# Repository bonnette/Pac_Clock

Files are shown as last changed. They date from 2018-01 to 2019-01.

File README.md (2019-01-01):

# Arduino Mega Pacman Clock
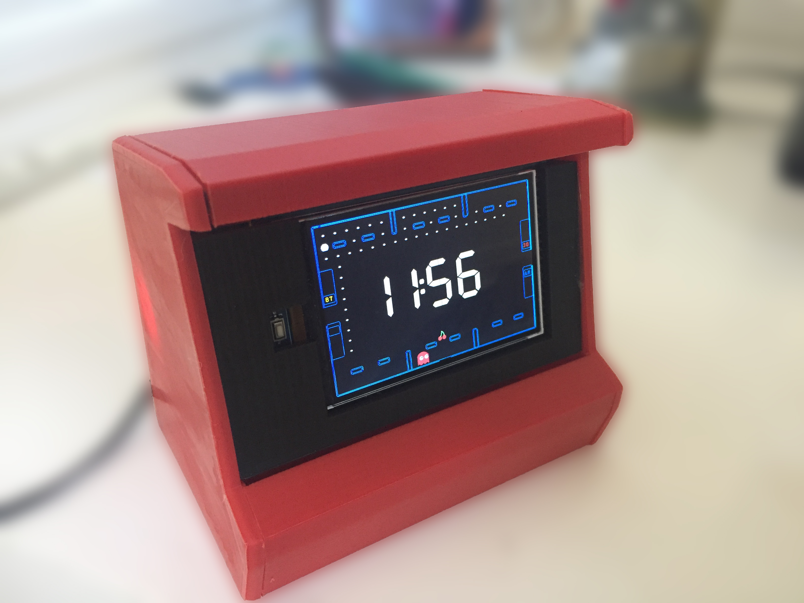
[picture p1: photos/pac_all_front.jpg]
Client Photo

<br/>
### There are more photos and information in the WIKI section of this repository
<br/>

This is modification of code from an Instructable by TechKiwiGadgets https://www.instructables.com/id/Retro-Pac-Man-Clock/
The purpose of the modification is to adapt the design to work with an HX8357C 480X320 TFT display <br/>(https://www.amazon.com/gp/product/B073R7Q8FF/ref=oh_aui_search_detailpage?ie=UTF8&psc=1).<br/>
And arduino Mega (https://www.amazon.com/gp/product/B01H4ZLZLQ/ref=oh_aui_search_detailpage?ie=UTF8&psc=1).
Additionally, because the display is not a touch display. Code has been added to use physical buttons to allow the time to be set on the clock.
<br />
The above photo is the clock in a 3d printed case. The case can be found on Thingiverse.com.<br/>
https://www.thingiverse.com/thing:2790349 <br/>
There is a newer version of the case that can be found here:<br/>
https://www.thingiverse.com/thing:3143466
<br />
The photo below shows the clock and RTC module.<br/>
Very bottom is a photo of the clock with larger font.
<br /><br />
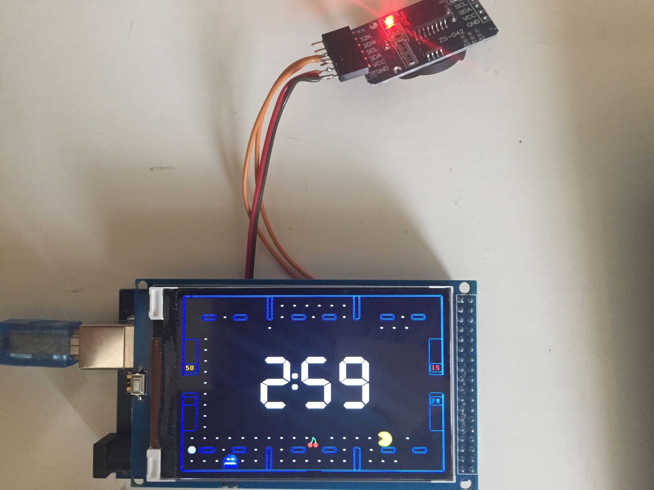
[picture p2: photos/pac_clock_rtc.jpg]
Client Photo

<br /><br />
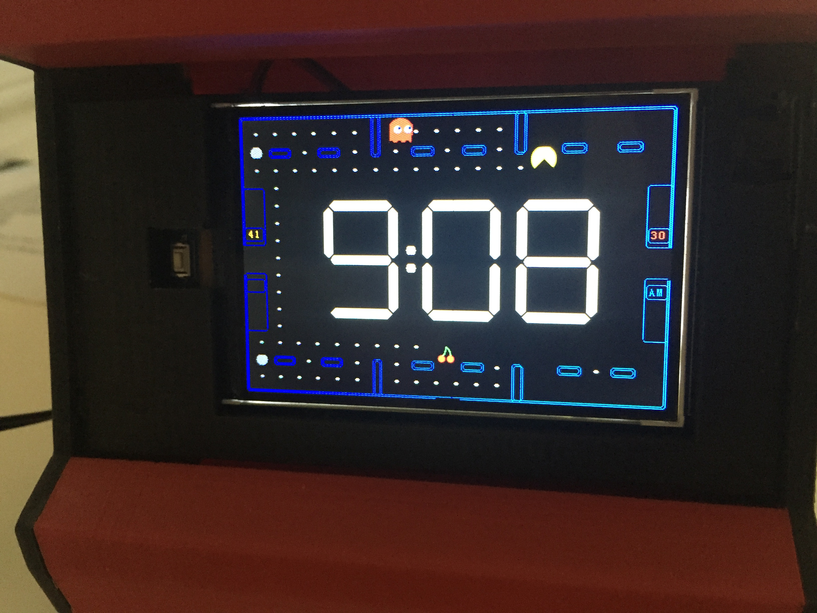
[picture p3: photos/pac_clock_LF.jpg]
Client Photo


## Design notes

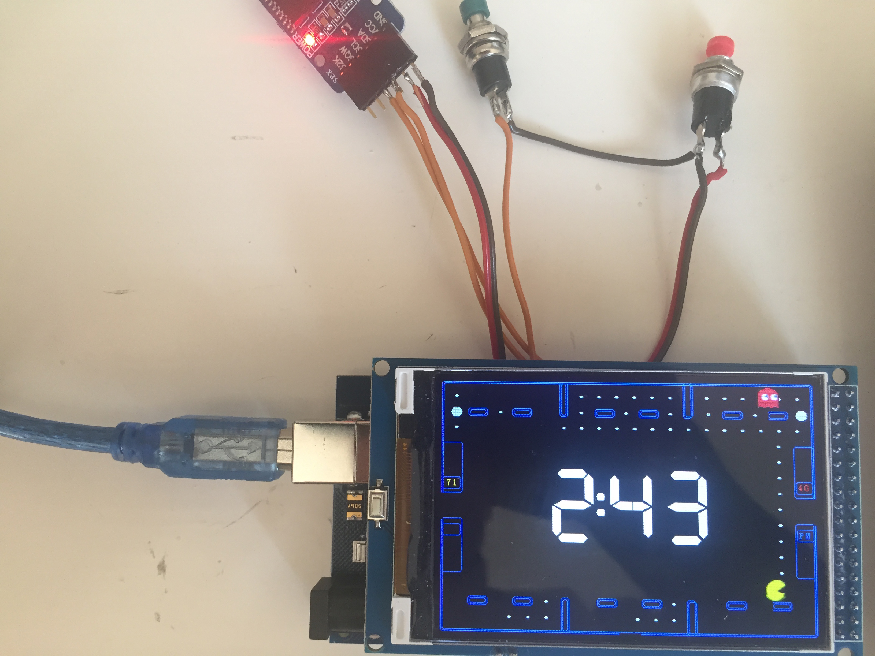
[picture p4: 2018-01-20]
photos/pac_clock_btn.jpg

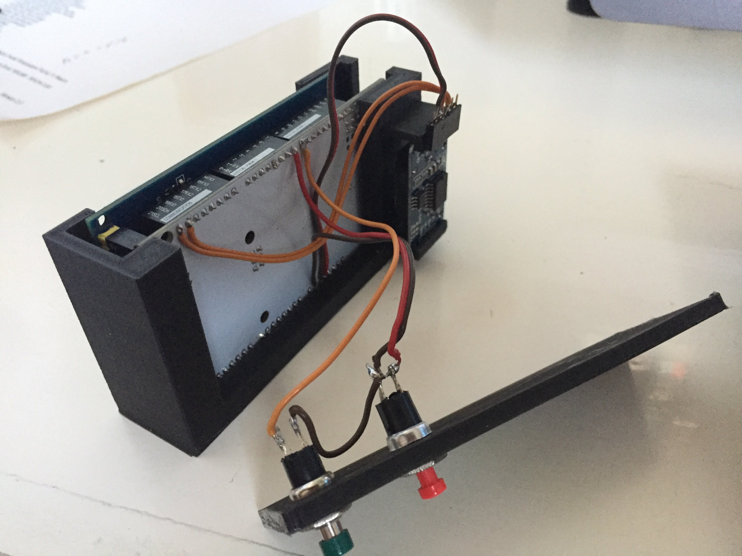
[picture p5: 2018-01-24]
photos/pac_cradle.jpg

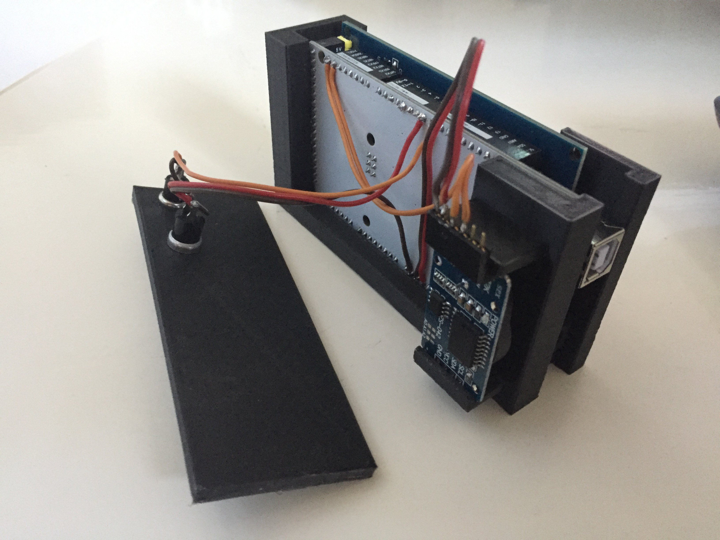
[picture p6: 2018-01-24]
photos/pac_cradle2.jpg

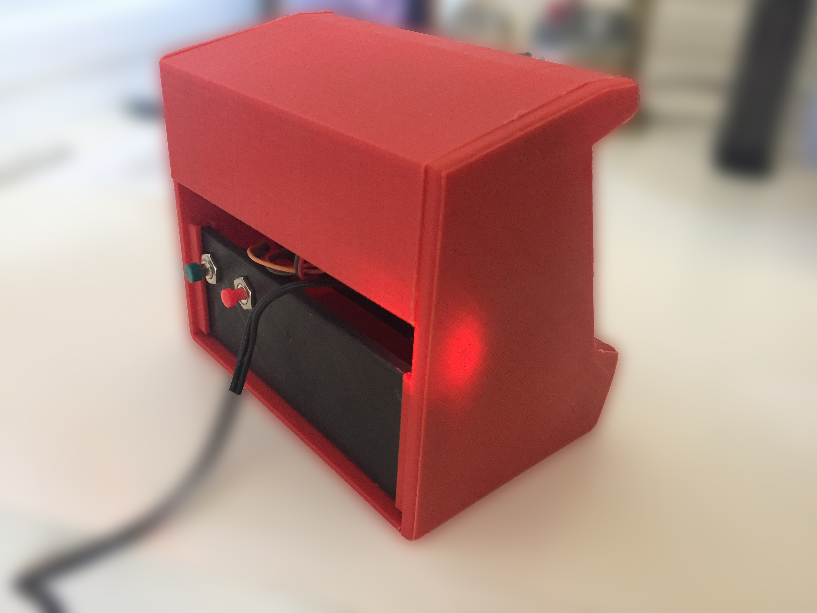
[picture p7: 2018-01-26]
photos/pac_all_back.jpg

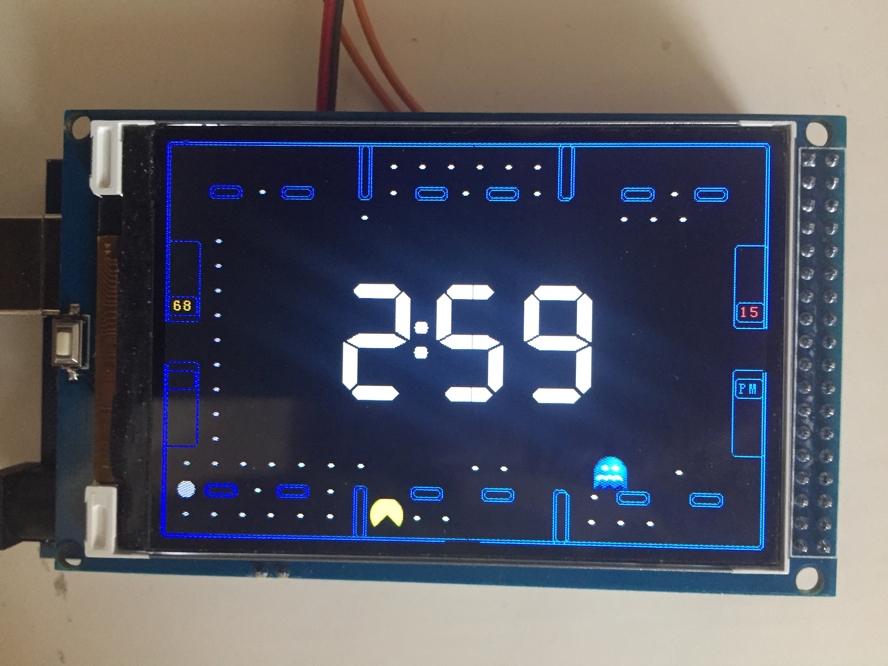
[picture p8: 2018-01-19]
photos/pac_clock.jpg

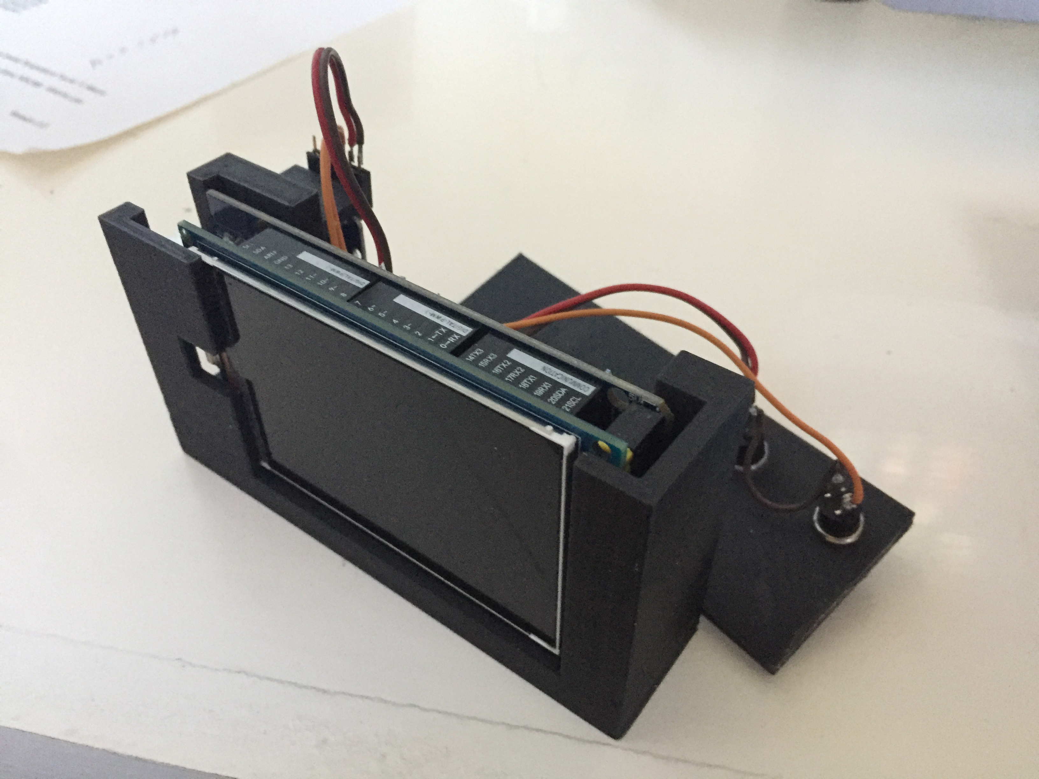
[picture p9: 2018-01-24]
photos/pac_cradle1.jpg

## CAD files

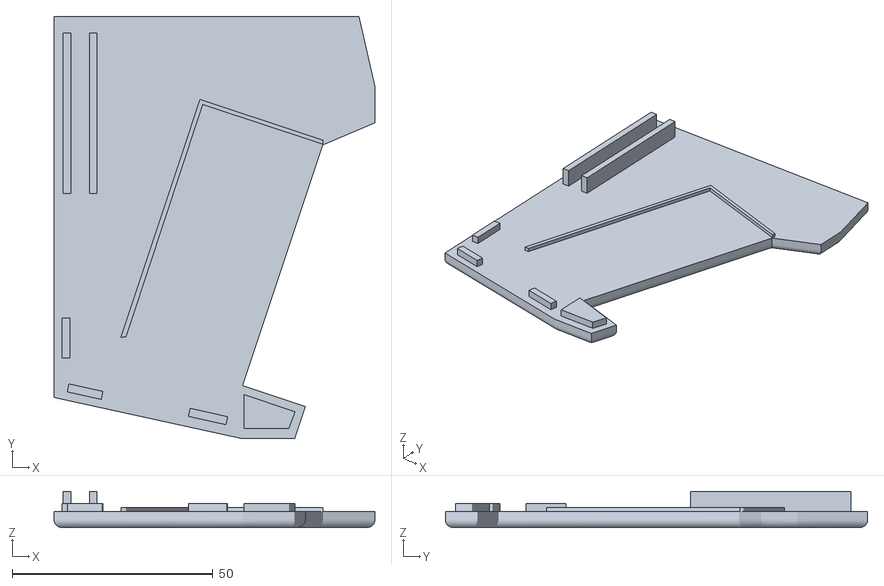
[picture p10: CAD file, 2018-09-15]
3D_Printed/pac_LS.stl
80.0 x 105.3 x 9.00

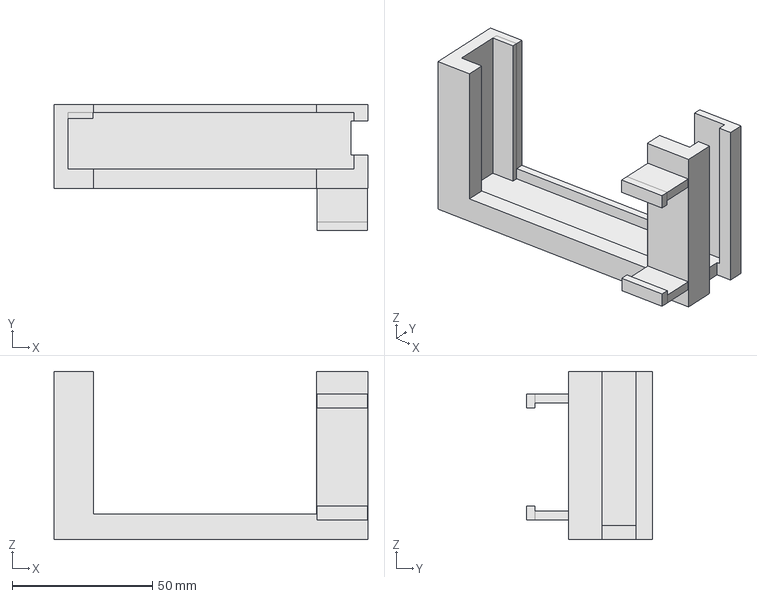
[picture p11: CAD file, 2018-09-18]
FreeCad/pac_clk_case_Cradle_HiLetgo.FCStd
112.0 x 45.0 x 60.0 mm

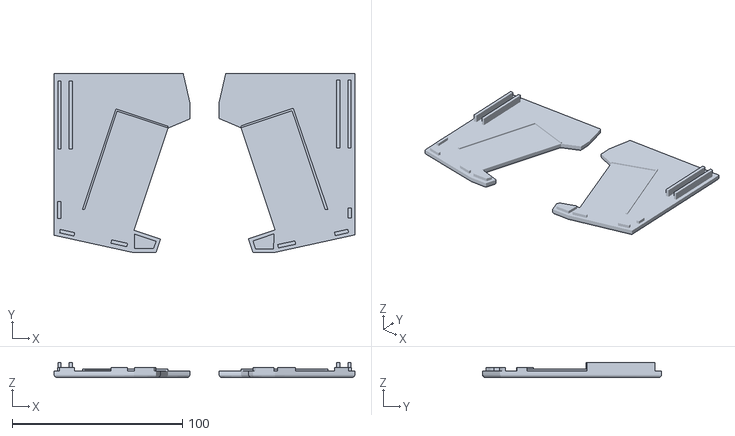
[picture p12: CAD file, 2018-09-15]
3D_Printed/pac_LS_RS.stl
177.0 x 105.5 x 9.00

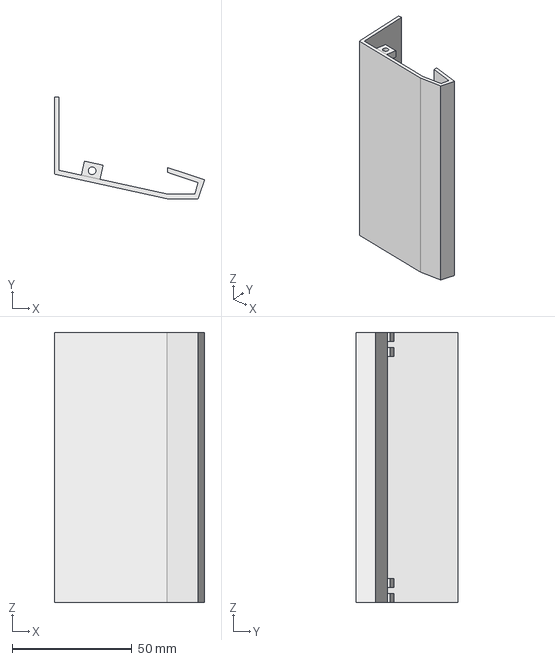
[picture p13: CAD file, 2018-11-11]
FreeCad/case_v2/pac_clk_case_Top.FCStd
62.7 x 42.3 x 112.5 mm

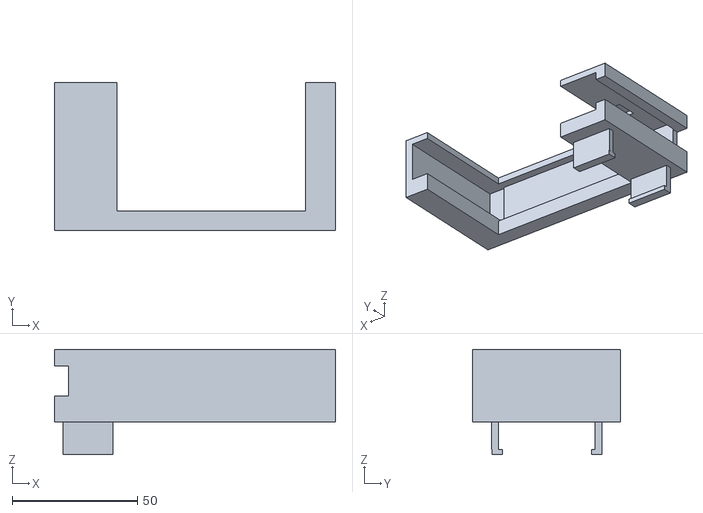
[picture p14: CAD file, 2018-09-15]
3D_Printed/pac_Cradle_no_reset.stl
112.0 x 59.0 x 42.0

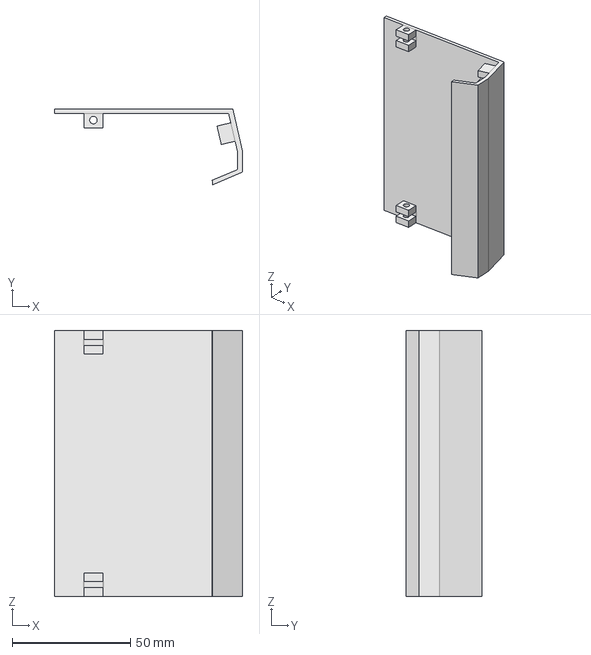
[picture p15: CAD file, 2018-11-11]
FreeCad/case_v2/pac_clk_case_Btm.FCStd
79.6 x 32.0 x 112.5 mm

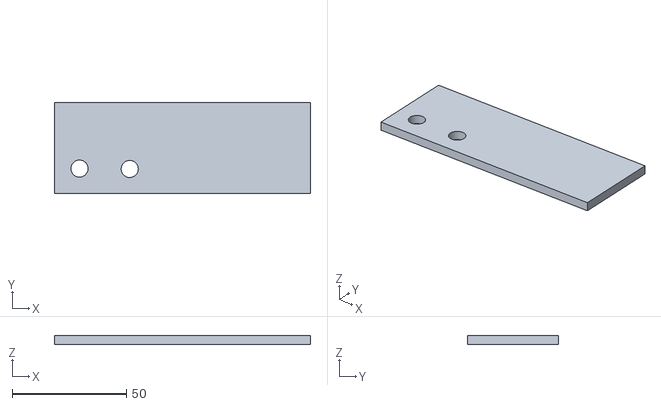
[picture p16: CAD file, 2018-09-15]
3D_Printed/pac_REAR_rnd.stl
112.0 x 40.0 x 4.00

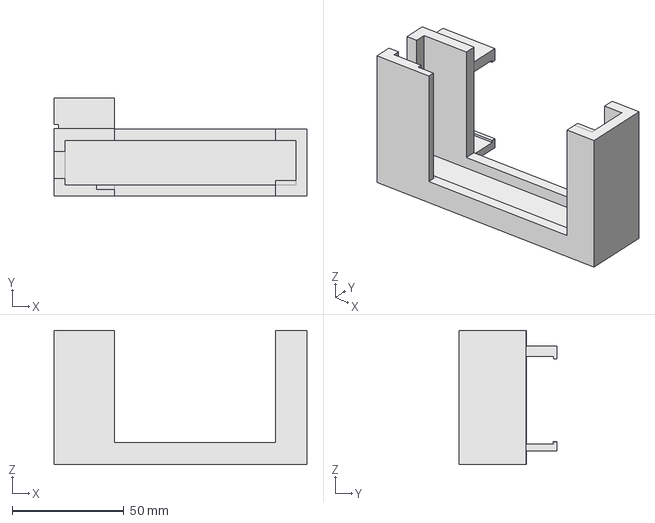
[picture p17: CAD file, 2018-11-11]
FreeCad/case_v2/pac_clk_case_Cradle.FCStd
113.0 x 44.0 x 60.0 mm

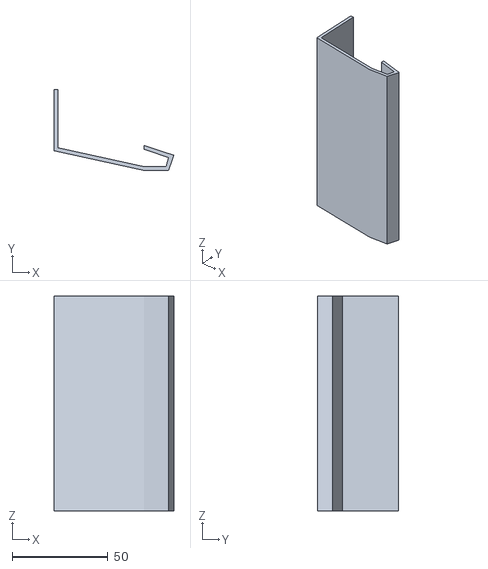
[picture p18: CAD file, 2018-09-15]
3D_Printed/pac_TOP.stl
62.7 x 42.3 x 112.5

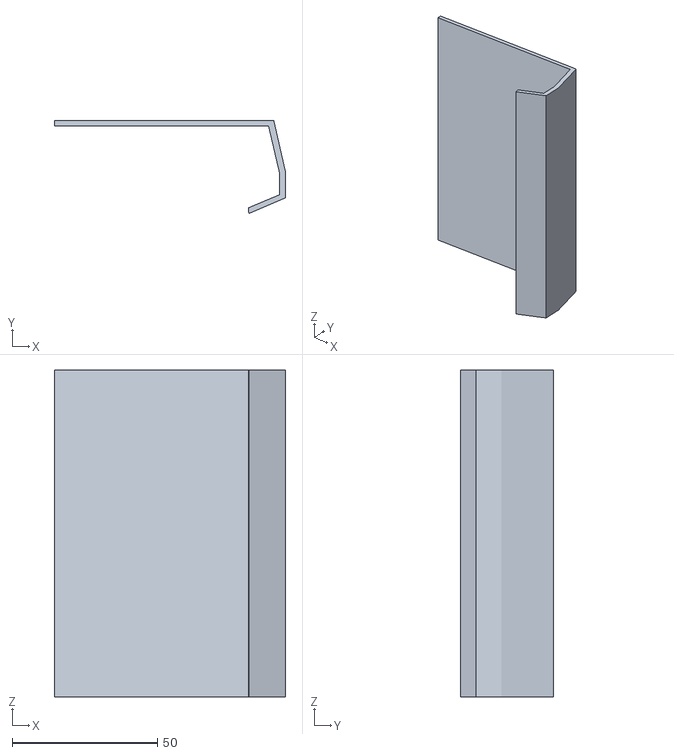
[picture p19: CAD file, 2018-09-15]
3D_Printed/pac_BTM.stl
79.6 x 32.0 x 112.5

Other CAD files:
FreeCad/case_v2/pac_clk_case_LS.FCStd
FreeCad/case_v2/pac_clk_case_RS.FCStd
3D_Printed/pac_RS.stl
FreeCad/pac_clk_case_Cradle_no_reset.FCStd
3D_Printed/pac_Cradle.stl
FreeCad/case_v2/pac_clk_case_Rear_sqr.FCStd
FreeCad/case_v2/pac_clk_case_Rear_rnd.FCStd
3D_Printed/pac_REAR_sqr.stl
FreeCad/pac_clk_case_Btm.FCStd
FreeCad/pac_clk_case_Cradle.FCStd
FreeCad/pac_clk_case_LS.FCStd
FreeCad/pac_clk_case_RS.FCStd
FreeCad/pac_clk_case_Top.FCStd

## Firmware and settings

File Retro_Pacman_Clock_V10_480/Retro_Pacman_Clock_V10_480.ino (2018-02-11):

 /*  Retro Pac-Man Clock
 Author: @TechKiwiGadgets Date 08/04/2017
  V5 
  - introduction of optional Backlight Dimmer Code
  - fix issues with Scoreboard display
 V6 
  - Introduce TEST button on Alarm screen to enable playing alarm sound
 V7 
 - Fix AM/PM error at midday
 V8
 - Add Ms Pac-Man feature in Setup menu
 V9
 - Fix issue with Ms Pac-Man leaving a trail at corners
 - Randomseed will shuffle the random function using Analog pin 0 
 V10 
 - Finally Retro PacMan Dots added and traditional gameplay- enjoy!!
 *****************************************************
 *Modified by Larry Bonnette for use with a non touch capable 480X320 TFT
 *****************************************************
*/
 
#include <UTFT.h> 
#include <URTouch.h>
#include <EEPROM.h>
#include <Time.h>  
#include <Wire.h>  
#include <DS1307RTC.h>  // a basic DS1307 library that returns time as a time_t

// Alarm Variables
boolean alarmstatus = false; // flag where false is off and true is on
boolean soundalarm = false; // Flag to indicate the alarm needs to be initiated
int alarmhour = 0;  // hour of alarm setting
int alarmminute = 0; // Minute of alarm setting
byte ahour; //Byte variable for hour
byte amin; //Byte variable for minute
int actr = 300; // When alarm sounds this is a counter used to reset sound card until screen touched
int act = 0;

boolean mspacman = false;  //  if this is is set to true then play the game as Ms Pac-man
// Changed Larry
//Dot Array - There are 112 Dots with 4 of them that will turn Ghost Blue!

byte dot[113]; // Where if dot is zero then has been gobbled by Pac-Man



// Initializes RTC time values: 
const int DS1307 = 0x68; // Address of DS1307 see data sheets

// Display Dimmer Variables
int dimscreen = 255; // This variable is used to drive the screen brightness where 255 is max brightness
int LDR = 100; // LDR variable measured directly from Analog 7

//==== Creating Objects

UTFT myGLCD(ILI9341_16,38,39,40,41); //Parameters should be adjusted to your Display/Schield model
//UTFT    myGLCD(SSD1289,38,39,40,41); //Parameters should be adjusted to your Display/Schield model
URTouch  myTouch( 6, 5, 4, 3, 2);


//==== Defining Fonts
extern uint8_t SmallFont[];
extern uint8_t BigFont[];
extern uint8_t SevenSegNumFont[];
extern uint8_t SevenSeg_XXXL_Num[];

extern unsigned int c_pacman[0x310]; // Ghost Bitmap Straight ahead


extern unsigned int ms_c_pacman_u[0x310]; // Ghost Bitmap Straight ahead
extern unsigned int ms_c_pacman_d[0x310]; // Ghost Bitmap Straight ahead
extern unsigned int ms_c_pacman_l[0x310]; // Ghost Bitmap Straight ahead
extern unsigned int ms_c_pacman_r[0x310]; // Ghost Bitmap Straight ahead

extern unsigned int ms_d_m_pacman[0x310]; // Ghost Bitmap Straight ahead
extern unsigned int ms_d_o_pacman[0x310]; // Ghost Bitmap Straight ahead
extern unsigned int ms_l_m_pacman[0x310]; // Ghost Bitmap Straight ahead
extern unsigned int ms_l_o_pacman[0x310]; // Ghost Bitmap Straight ahead
extern unsigned int ms_r_m_pacman[0x310]; // Ghost Bitmap Straight ahead
extern unsigned int ms_r_o_pacman[0x310]; // Ghost Bitmap Straight ahead
extern unsigned int ms_u_m_pacman[0x310]; // Ghost Bitmap Straight ahead
extern unsigned int ms_u_o_pacman[0x310]; // Ghost Bitmap Straight ahead

extern unsigned int d_m_pacman[0x310]; // Ghost Bitmap Straight ahead
extern unsigned int d_o_pacman[0x310]; // Ghost Bitmap Straight ahead
extern unsigned int l_m_pacman[0x310]; // Ghost Bitmap Straight ahead
extern unsigned int l_o_pacman[0x310]; // Ghost Bitmap Straight ahead
extern unsigned int r_m_pacman[0x310]; // Ghost Bitmap Straight ahead
extern unsigned int r_o_pacman[0x310]; // Ghost Bitmap Straight ahead
extern unsigned int u_m_pacman[0x310]; // Ghost Bitmap Straight ahead
extern unsigned int u_o_pacman[0x310]; // Ghost Bitmap Straight ahead



extern unsigned int ru_ghost[0x310]; // Ghost Bitmap Straight ahead
extern unsigned int rd_ghost[0x310]; // Ghost Bitmap Straight ahead
extern unsigned int rl_ghost[0x310]; // Ghost Bitmap Straight ahead
extern unsigned int rr_ghost[0x310]; // Ghost Bitmap Straight ahead
extern unsigned int fruit[0x310]; // Ghost Bitmap Straight ahead
extern unsigned int bluepacman[0x310]; // Ghost Bitmap Straight ahead

// Touch screen coordinates
boolean screenPressed = false;
int xT,yT;
int userT = 4; // flag to indicate directional touch on screen
boolean setupscreen = false; // used to access the setup screen
// Added flags for ph
boolean setupButton = HIGH;
boolean UpButton = HIGH;


// Fruit flags
boolean fruitgone = false;
boolean fruitdrawn = false;
boolean fruiteatenpacman = false;

//Pacman & Ghost kill flags
boolean pacmanlost = false;
boolean ghostlost = false;

//Alarm setup variables
boolean xsetup = false; // Flag to determine if existing setup mode

// Scorecard
int pacmanscore = 0;
int ghostscore = 0;

// Animation delay to slow movement down
int dly = 18; // Orignally 30

// Time Refresh counter 
int rfcvalue = 900; // wait this long until check time for changes
int rfc = 1;

// Pacman coordinates of top LHS of 28x28 bitmap
int xP = 4;
int yP = 148;
int P = 0;  // Pacman Graphic Flag 0 = Closed, 1 = Medium Open, 2 = Wide Open, 3 = Medium Open
int D = 0;  // Pacman direction 0 = right, 1 = down, 2 = left, 3 = up
int prevD;  // Capture legacy direction to enable adequate blanking of trail
int direct;   //  Random direction variable

// Ghost coordinates of top LHS of 28x28 bitmap
int xG = 452;
int yG = 148;
int GD = 2;  // Ghost direction 0 = right, 1 = down, 2 = left, 3 = up
int prevGD;  // Capture legacy direction to enable adequate blanking of trail
int gdirect;   //  Random direction variable 

// Declare global variables for previous time,  to enable refesh of only digits that have changed
// There are four digits that need to be drawn independently to ensure consisitent positioning of time
  int c1 = 20;  // Tens hour digit
  int c2 = 20;  // Ones hour digit
  int c3 = 20;  // Tens minute digit
  int c4 = 20;  // Ones minute digit


void setup() {

// Initialize Dot Array Larry
  for (int dotarray = 1; dotarray < 113; dotarray++) {    
    dot[dotarray] = 1;    
    }
  
//Initialize RTC
    Serial.begin(9600);
  // while (!Serial) ; // wait until Arduino Serial Monitor opens
  delay(200);
  setSyncProvider(RTC.get);   // the function to get the time from the RTC
  setSyncInterval(60); // sync the time every 60 seconds (1 minutes)
  if(timeStatus()!= timeSet){ 
     Serial.println("Unable to sync with the RTC");
     RTC.set(1408278800); // set the RTC to Aug 25 2014 9:00 am
     setTime(1408278800);
    }
    else{
     Serial.println("RTC has set the system time");   
    }

// Setup Alarm enable pin to play back sound on the ISD1820 board
   pinMode(8, OUTPUT); // D8 used to toggle sound
   digitalWrite(8,LOW);  // Set to low to turn off sound
   
// Setup Pin 9 of Arduino to LED A control brightness of the backlight. 
// This is done by firstly disconnecting Pin 19 of the TFT screen
// Followed by connecting D9 of Arduino to Pin 19 of TFT via a 47 ohm resistor
   pinMode(9, OUTPUT); // D9 used to PWM voltage to backlight on TFT screen
   analogWrite(9, 255); // Controls brightness 0 is Dark, Ambient room is approx 25 and 70 is direct sunlight

// Set time set buttons on Pin 7 and 8
// pin 7 is select, pin 8 is up/down
pinMode(7, INPUT_PULLUP); // Select button
pinMode(8, INPUT_PULLUP); // Up button

// Randomseed will shuffle the random function
randomSeed(analogRead(0));

  // Initiate display
  myGLCD.InitLCD();
  myGLCD.clrScr();
  myTouch.InitTouch();
  myTouch.setPrecision(PREC_LOW);
  
 
  drawscreen(); // Initiate the game
  UpdateDisp(); // update value to clock 


}

void loop() {

// Check physical Buttons
setupButton = digitalRead(7); // setup button  
UpButton = digitalRead(8); // Up button


// Set Screen Brightness
// Check the ambient light and adjust LED brightness to suit Ambient approx 500 dark is below 100
LDR = analogRead(A7);

/* Test value range of LDR
  myGLCD.setColor(237, 28, 36);
  myGLCD.setBackColor(0, 0, 0);
  myGLCD.printNumI(LDR,250,60,3);

if (LDR >=121){
    dimscreen = 255;
   } 
   
if (LDR <=120)   {  
    dimscreen = 20;
   }    
*/
/*
//Print positions for testing
  myGLCD.setFont(BigFont);
  myGLCD.setColor(0, 0, 0);
  myGLCD.setBackColor(114, 198, 206);
  myGLCD.printNumI(xG,228,200); // Print xP
  myGLCD.printNumI(yG,228,220); // Print yP
*/

dimscreen = (LDR/4)+5;

if (dimscreen >= 255){
  dimscreen = 255;
  }
analogWrite(9, dimscreen); // Controls brightness 0 is Dark, Ambient room is approx 25 and 70 is direct sunlight 
  
//Print scoreboard

if((ghostscore >= 95)||(pacmanscore >= 95)){ // Reset scoreboard if over 95
ghostscore = 0;
pacmanscore = 0;

  for (int dotarray = 1; dotarray < 113; dotarray++) {
    
    dot[dotarray] = 1;
    
    }

// Blank the screen across the digits before redrawing them
  myGLCD.setColor(0, 0, 0);
  myGLCD.setBackColor(0, 0, 0);

//    myGLCD.fillRect(299, 87, 314, 97); // Blankout ghost score  
    myGLCD.fillRect(399, 87, 414, 97); // Blankout ghost score diff=6
//    myGLCD.fillRect(7, 87, 22, 97);   // Blankout pacman score
    myGLCD.fillRect(107, 87, 122, 97);   // Blankout pacman score

drawscreen(); // Redraw dots  
}
  
  myGLCD.setFont(SmallFont);

// Account for position issue if over or under 10

if (ghostscore >= 10){
  myGLCD.setColor(237, 28, 36);
  myGLCD.setBackColor(0, 0, 0);
//  myGLCD.printNumI(ghostscore,299,87);
  myGLCD.printNumI(ghostscore,459,127);
} else {
  myGLCD.setColor(237, 28, 36);
  myGLCD.setBackColor(0, 0, 0);
//  myGLCD.printNumI(ghostscore,307,87);  // Account for being less than 10
  myGLCD.printNumI(ghostscore,467,127);  // Account for being less than 10
}

if (pacmanscore >= 10){
  myGLCD.setColor(248, 236, 1);
  myGLCD.setBackColor(0, 0, 0);
//  myGLCD.printNumI(pacmanscore,7,87);  
  myGLCD.printNumI(pacmanscore,7,127);  

} else{
  myGLCD.setColor(248, 236, 1);
  myGLCD.setBackColor(0, 0, 0);
//  myGLCD.printNumI(pacmanscore,15,87);  // Account for being less than 10
  myGLCD.printNumI(pacmanscore,15,127);  // Account for being less than 10
} 
  
  // Draw fruit
if ((fruitdrawn == false)&&(fruitgone == false)){ // draw fruit and set flag that fruit present so its not drawn again
//    myGLCD.drawBitmap (146, 168, 28, 28, fruit); //   draw fruit 
    myGLCD.drawBitmap (230, 248, 28, 28, fruit); //   draw fruit 
    fruitdrawn = true;
}  

// Redraw fruit if Ghost eats fruit only if Ghost passesover 216 or 238 on the row 248
if ((fruitdrawn == true)&&(fruitgone == false)&&(xG == 192)&&(yG == 248)){
    myGLCD.drawBitmap (230, 248, 28, 28, fruit); //   draw fruit
}

if ((fruitdrawn == true)&&(fruitgone == false)&&(xG == 262)&&(yG == 248)){
    myGLCD.drawBitmap (230, 248, 28, 28, fruit); //   draw fruit 
}

// Redraw fruit on Ghost down motion
if ((fruitdrawn == true)&&(fruitgone == false)&&(xG == 228)&&(yG == 288)){
    myGLCD.drawBitmap (230, 248, 28, 28, fruit); //   draw fruit 
}

// Award Points if Pacman eats Fruit
if ((fruitdrawn == true)&&(fruitgone == false)&&(xP == 228)&&(yP == 248)){
  fruitgone = true; // If Pacman eats fruit then fruit disappears  
  pacmanscore = pacmanscore + 5; //Increment pacman score
}



// Read the current date and time from the RTC and reset board
rfc++;
  if (rfc >= rfcvalue) { // count cycles and print time
    UpdateDisp(); // update value to clock then ...
     fruiteatenpacman =  false; // Turn Ghost red again  
     fruitdrawn = false; // If Pacman eats fruit then fruit disappears
     fruitgone = false;
     // Reset every minute both characters
     pacmanlost = false;
     ghostlost = false;
     dly = 18; // reset delay
     rfc = 0;
     
  }

//=== Check if Alarm needs to be sounded
   if (alarmstatus == true){  
     if ( (alarmhour == hour()) && (alarmminute == minute())) {  // Sound the alarm        
           soundalarm = true;
       }     
   }

//=== Start Alarm Sound - Sound pays for 10 seconds then will restart at 20 second mark

if ((alarmstatus == true)&&(soundalarm==true)){ // Set off a counter and take action to restart sound if screen not touched

    if (act == 0) { // Set off alarm by toggling D8, recorded sound triggered by LOW to HIGH transition
        digitalWrite(8,HIGH); // Set high
        digitalWrite(8,LOW); // Set low
        UpdateDisp(); // update value to clock 
    }
    act = act +1;
   
    if (act == actr) { // Set off alarm by toggling D8, recorded sound triggered by LOW to HIGH transition
        digitalWrite(8,HIGH); // Set high
        digitalWrite(8,LOW); // Set low
        act = 0; // Reset counter hopfully every 20 seconds
    } 

}

// Check if user input to touch screen
// UserT sets direction 0 = right, 1 = down, 2 = left, 3 = up, 4 = no touch input

// Setup button pressed 
     myTouch.read();
// if (myTouch.dataAvailable() && !screenPressed)
 if (setupButton == LOW){
    xT = myTouch.getX();
    yT = myTouch.getY();        
    // Capture direction request from user
    if ((xT>=1) && (xT<=80) && (yT>=80) && (yT<=160)) { // Left
        userT = 2; // Request to go left   
    }
    if ((xT>=240) && (xT<=318) && (yT>=80) && (yT<=160)) { // Right
        userT = 0; // Request to go right   
    }
    if ((xT>=110) && (xT<=210) && (yT>=1) && (yT<=80)) { // Up
        userT = 3; // Request to go Up   
    }
     if ((xT>=110) && (xT<=210) && (yT>=160) && (yT<=238)) { // Down
        userT = 1; // Request to go Down   
    }
 
 // **********************************
 // ******* Enter Setup Mode *********
 // **********************************
 
//    if (((xT>=120) && (xT<=200) && (yT>=105) && (yT<=140)) &&  (soundalarm !=true)) { // Call Setup Routine if alarm is not sounding
      if (setupButton == LOW){
        setupButton = HIGH;
        xsetup = true;  // Toggle flag
        clocksetup(); // Call Clock Setup Routine 
        UpdateDisp(); // update value to clock
        
    } else  // If centre of screen touched while alarm sounding then turn off the sound and reset the alarm to not set 
    
    if (((xT>=120) && (xT<=200) && (yT>=105) && (yT<=140)) && ((alarmstatus == true) && (soundalarm ==true))) {
     
      alarmstatus = false;
      soundalarm = false;
      digitalWrite(8,LOW); // Set low
    } 
    
    
 
    if(pacmanlost == false){ // only apply requested changes if Pacman still alive

       if (userT == 2 && D == 0 ){ // Going Right request to turn Left OK
         D = 2;
         }
       if (userT == 0 && D == 2 ){ // Going Left request to turn Right OK
         D = 0;
         }
       if (userT == 1 && D == 3 ){ // Going Up request to turn Down OK
         D = 1;
         }
       if (userT == 3 && D == 1 ){ // Going Down request to turn Up OK
         D = 3;
         }
      }
         screenPressed = true;
   }
    // Doesn't allow holding the screen / you must tap it
    else if ( !myTouch.dataAvailable() && screenPressed){
      screenPressed = false;
   }

// Pacman Captured
// If pacman captured then pacman dissapears until reset
if ((fruiteatenpacman == false)&&(abs(xG-xP)<=5)&&(abs(yG-yP)<=5)){ 
// firstly blank out Pacman
    myGLCD.setColor(0,0,0);
    myGLCD.fillRect(xP, yP, xP+27, yP+27); 

  if (pacmanlost == false){
    ghostscore = ghostscore + 15;  
  }
  pacmanlost = true;
 // Slow down speed of drawing now only one moving charater
  dly = 28;
  }
 
if (pacmanlost == false) { // Only draw pacman if he is still alive


// Draw Pac-Man
drawPacman(xP,yP,P,D,prevD); // Draws Pacman at these coordinates
  

// If Pac-Man is on a dot then print the adjacent dots if they are valid

  myGLCD.setColor(200, 200, 200);
  
// Check Rows
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

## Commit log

2018-01-19 Fixed Ghost Fruit
    Added repaint of fruit if ghost goes i down direction
    [Retro_Pacman_Clock_V10_480.ino]
2018-01-19 impliment setup button
2018-01-20 Button Implimentation
2018-01-21 modified button handleing
2018-01-26 Added case photos
2018-01-29 More fruit fix
    Redraw dot 90 when fruit drawn
    [Retro_Pacman_Clock_V10_480_LG.ino]
2018-09-18 FreeCad source Files
    [pac_clk_case_Btm.FCStd, pac_clk_case_Cradle.FCStd, pac_clk_case_Cradle_HiLetgo.FCStd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]
2018-11-11 Added case version 2
    Better top fit
    Screw holes and nut holders
    [pac_clk_case_Btm.FCStd, pac_clk_case_Cradle.FCStd, pac_clk_case_LS.FCStd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]
2019-01-01 Update README.md
    Added new version of case
2019-01-05 Add files via upload
    added clock wireing
